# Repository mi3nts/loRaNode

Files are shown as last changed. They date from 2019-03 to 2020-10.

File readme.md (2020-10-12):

# LoRa Node 
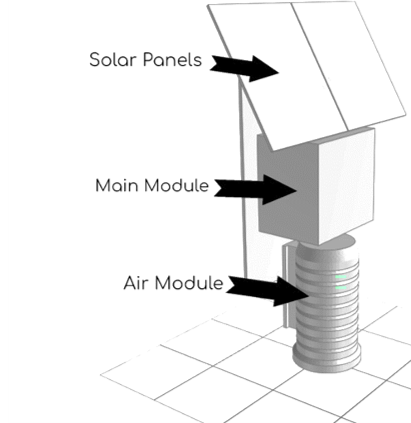
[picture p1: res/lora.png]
LoraNode

</br>
</br>

## A Guide to Using the Low-Cost Sensor Network
written by, Daniel Kiv (github: marchfori)

### Basics

1. Sensors Nodes (arduino)

### Sensors
2. Physical Characteristics
-Dimensions
-Weight
-Power Requirements

### Gateway Node (Raspberry Pi 3)
3.Useful Links

### Adjustments
4.Setting up the External Hard drive
5.Connecting to an external network
6.Adjustments to the PPD42NS

### Basics

The purpose of this documentation is to show how to start up and maintain the network
of low-cost sensors that will begin deployment in the North Texas area. With the increase
in particulate emissions over the years, there is a need to be aware of the implications
of toxic airbourne particles. These can have negative health outcomes on the population.
Currently, air quality sensors are spaced far and wide from each other collecting data at 
large time frames. They can also be often expensive. This project seeks to solve these 
issues and presents a low cost sensor network using a novel network communication known as
LoRaWAN, a set of arduinos, and a gateway linux based Raspbery Pi 3. Combined with the 
calibration technique using machine learning algorithms, this sensor network can effectively
provide the public with an accurate representation of air quality.

#### Sensor Nodes (arduino)
- Seeeduino w/ LoRaWAN and GPS capabilities

Uses a set of 10 arduino based nodes and 1 gateway Raspberry Pi 3.

- [Seeeduino LoRaWAN with GPS](https://www.google.com/search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)
- [Grove Dust Sensor](https://www.seeedstudio.com/Grove-Dust-Sensor-PPD42NS.html)
- [Grove Barometer Sensor: I2C protocol](https://www.seeedstudio.com/Grove-Barometer-Sensor-BMP28-p-2652.html)
- [Raspberry Pi 3 Model B](https://www.amazon.com/Raspberry-Pi-Model-Motherboard-Element/dp/B07CTF2GWR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)
- [RHFoM301 module: serves as the communication bridge for the Raspberry Pi 3](http://www.risinghf.com/#/product-details?product_id=6&lang=en%2F)
- [BME280 w/ Temperature, Pressure, & Humidity Readings](https://www.adafruit.com/product/2652?gclid=CJvFq_q63-ICFUi1wAod5RsHjw)
- [Grove Multichannel Gas Sensor](https://www.arrow.com/en/products/101020088/seeed-technology-limited?gclid=CKqP4Za73-ICFdm1wAodyJsA8g) 

## Sensors
These sensors are attached to the device

| Sensor Name | Description | Interface |
| ---- | ---- | ---- |
| Grove Dust Sensor | Measures low pulse occupancy time as a correlate to particular matter. | Digital Pin |
| Grove Barometer | Measures temperature (Celcius) and atmospheric pressure | I2C |
| Grove Multichannel Gas Sensor | Measures Carbon Monoxide, Nitrogen Dioxide, Ethanol, Hydrogen, Ammonia, Methane, Propane,and Isobutane in ppm. | I2C |

#### Physical Characteristics

**Dimensions** (L x W x H)
Seeduino device dimensions with add-ons: 65mm x 55mm x 45mm.
Gateway device dimensions (without antenna): 85mm x 55mm x 30mm.
Seeeduino device enclosure: 120mm x 120mm x 275 mm

**Weight**
Seeeduino device weight with add-ons: 0.25kg
Gateway device weight: 0.20kg
Seeeduino device with enclosure: 0.60kg

**Power Requirements**
Average power consumption on standby: 1.1W
Average power consumption during transmission 1.2W
Voltage usage: 4.91V
Current usage: 0.20A

- [3.7V Lithium Ion Battery](https://www.amazon.com/Lithium-Battery-Connector-LP803860-2000mAh/dp/B07CZFMFB3)
- [3W SEEED Solar Panel](https://cpc.farnell.com/seeed-studio/313070001/solar-panel-138x160-3w/dp/MK00376)

### Gateway Node (Raspberry Pi 3)

Used to collect signal broadcasts from surrounding nodes.

#### Useful links

[Here](https://github.com/mi3nts/loRaNode) is the link to the sensor node's software. 
If there are issues please contact me.

There is also software that synchornizes and creates the formatting for the data 
aggregation on the gateway node.

### Adjustments

#### Setting up the External hard drive

- Checking if the HD is connected 
```
sudo lshw -class disk -short 
```
Be sure the hard drive you want to use is formatted in the **_ext4_** filesystem. 

- Mounting the HD
```
sudo su
mount /dev/sda1 /mnt
```

- Transfer your root partition to the new drive:
```
sudo rsync -axv / /mnt
cp /boot/cmdline.txt /boot/cmdline.txt.bak
nano /boot/cmdline.txt

```
- Change the lines as follows:

```
dwc_otg.lpm_enable=0 console=serial0,115200 console=tty1 root=/dev/sda1 rootfstype=ext4 elevator=deadline fsck.repair=yes rootwait rootdelay=5
```
- Chnaging the Boot Order 
```
nano /mnt/etc/fstab
```
Then add the following line:
```
/dev/sda1       /               ext4    defaults,noatime  0       1
```
Make sure to get the spacing right 

Comment the SD Boot 
```
#/dev/mmcblk0p7  /               ext4    defaults,noatime  0       1

```

Then restart the system.

#### Connecting to an external network

```
sudo nano
/etcwpa_supplicant/wpa_supplicant.conf

   network={
    ssid="Test Wifi Network"
    psk="SecretPassWord"
    }
    
 sudo systemctl status pktfwd
 sudo systemctl enable pktfwd
 sudo systemctl restart pktfwd
 
 **mysql -u root -p**
 ```
 
#### Additional Modifications made to the PPD42NS
##### PPD42NS
shinyei
     <br/>
     
The pins are labeled as '**thresh**', '**P1**', '**+5v**', '**P2**, and '**grnd**'  going from left to write on the figure given above. 

 - Addition of a 10K resisitor between the threshold pin and ground:
 A good read on the mechanism followed is given [here](http://takingspace.org/wp-content/uploads/ShinyeiPPD42NS_Deconstruction_TracyAllen.pdf).
[useful](https://www.shadowandy.net/2015/05/arduino-dust-sensor.htm)
 -  Capable of dual output
 
 ##### color code
 
 - p1: green - D3
 - p2: blue - D4

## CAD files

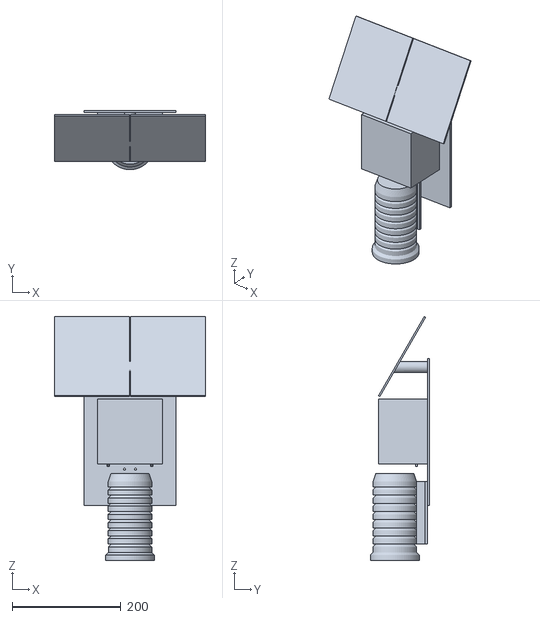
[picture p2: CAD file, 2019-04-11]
3D model/loRaNode2019.stl
278.0 x 109.0 x 448.5

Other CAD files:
3D model/loRaModel.fcstd

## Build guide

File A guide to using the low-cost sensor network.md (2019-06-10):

# A Guide to Using the Low-Cost Sensor Network
written by, Daniel Kiv (github: marchfori)

## Basics

1. Sensors Nodes (arduino)

## Sensors
2. Physical Characteristics
-Dimensions
-Weight
-Power Requirements

## Gateway Node (Raspberry Pi 3)
3.Useful Links

## Adjustments
4.Setting up the External Hard drive
5.Connecting to an external network
6.Adjustments to the PPD42NS

## Basics

The purpose of this documentation is to show how to start up and maintain the network
of low-cost sensors that will begin deployment in the North Texas area. With the increase
in particulate emissions over the years, there is a need to be aware of the implications
of toxic airbourne particles. These can have negative health outcomes on the population.
Currently, air quality sensors are spaced far and wide from each other collecting data at 
large time frames. They can also be often expensive. This project seeks to solve these 
issues and presents a low cost sensor network using a novel network communication known as
LoRaWAN, a set of arduinos, and a gateway linux based Raspbery Pi 3. Combined with the 
calibration technique using machine learning algorithms, this sensor network can effectively
provide the public with an accurate representation of air quality.

###### Sensor Nodes (arduino)
- Seeeduino w/ LoRaWAN and GPS capabilities

Uses a set of 10 arduino based nodes and 1 gateway Raspberry Pi 3.

- [Seeeduino LoRaWAN with GPS](https://www.google.com/search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)
- [Grove Dust Sensor](https://www.seeedstudio.com/Grove-Dust-Sensor-PPD42NS.html)
- [Grove Barometer Sensor: I2C protocol](https://www.seeedstudio.com/Grove-Barometer-Sensor-BMP28-p-2652.html)
- [Raspberry Pi 3 Model B](https://www.amazon.com/Raspberry-Pi-Model-Motherboard-Element/dp/B07CTF2GWR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)
- [RHFoM301 module: serves as the communication bridge for the Raspberry Pi 3](http://www.risinghf.com/#/product-details?product_id=6&lang=en%2F)
- [BME280 w/ Temperature, Pressure, & Humidity Readings](https://www.adafruit.com/product/2652?gclid=CJvFq_q63-ICFUi1wAod5RsHjw)
- [Grove Multichannel Gas Sensor](https://www.arrow.com/en/products/101020088/seeed-technology-limited?gclid=CKqP4Za73-ICFdm1wAodyJsA8g) 

## Sensors
These sensors are attached to the device

| Sensor Name | Description | Interface |
| ---- | ---- | ---- |
| Grove Dust Sensor | Measures low pulse occupancy time as a correlate to particular matter. | Digital Pin |
| Grove Barometer | Measures temperature (Celcius) and atmospheric pressure | I2C |
| Grove Multichannel Gas Sensor | Measures Carbon Monoxide, Nitrogen Dioxide, Ethanol, Hydrogen, Ammonia, Methane, Propane,and Isobutane in ppm. | I2C |

###### Physical Characteristics

**Dimensions** (L x W x H)
Seeduino device dimensions with add-ons: 65mm x 55mm x 45mm.
Gateway device dimensions (without antenna): 85mm x 55mm x 30mm.
Seeeduino device enclosure: 120mm x 120mm x 275 mm

**Weight**
Seeeduino device weight with add-ons: 0.25kg
Gateway device weight: 0.20kg
Seeeduino device with enclosure: 0.60kg

**Power Requirements**
Average power consumption on standby: 1.1W
Average power consumption during transmission 1.2W
Voltage usage: 4.91V
Current usage: 0.20A

- [3.7V Lithium Ion Battery](https://www.amazon.com/Lithium-Battery-Connector-LP803860-2000mAh/dp/B07CZFMFB3)
- [3W SEEED Solar Panel](https://cpc.farnell.com/seeed-studio/313070001/solar-panel-138x160-3w/dp/MK00376)

## Gateway Node (Raspberry Pi 3)

Used to collect signal broadcasts from surrounding nodes.

###### Useful links

[Here](https://github.com/mi3nts/loRaNode) is the link to the sensor node's software. 
If there are issues please contact me.

There is also software that synchornizes and creates the formatting for the data 
aggregation on the gateway node.

## Adjustments

###### Setting up the external hard drive

Be sure the hard drive you want to use is formatted in the **_ext4_** filesystem.
I used gparted. Then perform the following the commands in order to mount and 
transfer your root partition to the new drive:

```
sudo su
mount /dev/sda1 /mnt
sudo rsync -axv/ /mnt
cp /boot/cmdline.txt/boot/cmdline.txt.bak
nano /boot/cmdline.txt
```
Change the lines as follows:

```
dwc_otg.lpm_enable=0
console=serial0,115200 console=tty1
root=/dev/sda1 rootfstype=ext4 elevator=deadline
fsck.repair=yes rootwait rootdelay=5

nano /mnt/etc/fstab
```

Then add the following line:

```
/dev/sda1 / ext4
defaults,noatime 0

```

Then restart the system.

###### Connecting to an external network

```
sudo nano
/etcwpa_supplicant/wpa_supplicant.conf

   network={
    ssid="Test Wifi Network"
    psk="SecretPassWord"
    }
    
 sudo systemctl status pktfwd
 sudo systemctl enable pktfwd
 sudo systemctl restart pktfwd
 
 **mysql -u root -p**
 ```
 
 ######Adjustments to the PPD42NS
 
 [Diagram of PPD42NS](https://images.app.goo.gl/Z5E9UCeksRY98rgn6)
 
 The pins are labeled as 'thresh', 'P1', '+5V', 'P2', and 'grnd' going from left to right on the figure given above. Addition of a 10K resistor between the threshold pin and ground: A good read on the mechanism followed is given [here](http://takingspace.org/wp-content/uploads/ShinyeiPPD42NS_Deconstruction_TracyAllen.pdf)
 
- Capable of dual output

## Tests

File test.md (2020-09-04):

after first boot of the rasberi pi 
us: rxhf
pw: risinghf

# Expand SD
sudo raspi-config

# install Dependancies
```
sudo apt-get install screen
sudo apt-get install python3-pip
sudo pip3 install getmac
sudo pip3 install pyserial
sudo pip3 install netifaces
sudo pip3 install pynmea2
```
# Install crontab with Nano 
export VISUAL=nano; crontab -e

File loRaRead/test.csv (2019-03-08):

DateTime | NH3 | CO | NO2 | C3H8 | C4H10 | CH4 | H2 | C2H5OH | LowPulseOccupancy | lpoRatio | dustconc | Temperature | Pressure | Humidity
2.0 | 0.0 | 0.0 | 0.62 | 22.14 | 100712.0 | 16.0 | nan | nan
1.0 | 0.02 | 0.0 | 6.91 | 1.25 | 1423.63 | 865.82 | 3401.32 | 1.46
2.0 | 0.0 | 0.0 | 0.62 | 22.13 | 100711.0 | 16.0 | nan | nan
1.0 | 0.02 | 0.0 | 6.91 | 1.23 | 1384.14 | 845.38 | 3401.32 | 1.46
2.0 | 0.0 | 0.0 | 0.62 | 22.14 | 100712.0 | 16.0 | nan | nan
1.0 | 0.02 | 0.0 | 6.91 | 1.24 | 1403.69 | 855.51 | 3401.32 | 1.46
2.0 | 0.0 | 0.0 | 0.62 | 22.14 | 100710.0 | 16.0 | nan | nan
1.0 | 0.02 | 0.0 | 6.91 | 1.23 | 1384.14 | 845.38 | 3401.32 | 1.46
2.0 | 0.0 | 0.0 | 0.62 | 22.14 | 100714.0 | 16.0 | nan | nan
1.0 | 0.02 | 0.0 | 6.87 | 1.25 | 1423.63 | 865.82 | 3317.33 | 1.45
1.0 | 0.06 | 0.0 | 45.8 | 3.56 | 6919.4 | 3314.88 | 3720184.0 | 26.24
1.0 | 0.08 | 0.0 | 9.57 | 2.25 | 3466.94 | 1843.48 | 11353.08 | 2.41
2.0 | 10510.0 | 0.21 | 109.77 | 19.42 | 100748.0 | 20.0 | nan | nan
1.0 | 0.08 | 0.0 | 8.93 | 2.11 | 3140.91 | 1695.2 | 8782.5 | 2.16
2.0 | 0.0 | 0.0 | 0.62 | 19.44 | 100748.0 | 20.0 | nan | nan
1.0 | 0.09 | 0.0 | 8.5 | 2.01 | 2910.14 | 1588.84 | 7313.09 | 2.01
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

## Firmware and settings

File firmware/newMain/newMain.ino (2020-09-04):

/* 
 * Written by Daniel Kiv
 * Version 011020
 * 
 * Acknowledgements
 * Lakitha, Adam, Nora, Shrey
 */

#include <Arduino.h>
#include <Seeed_BME280.h>
#include <Wire.h>
#include <LoRaWan.h>
#include <avr/dtostrf.h>
#include "MutichannelGasSensor.h"
#include <SeeedOLED.h>
#include <Adafruit_INA219.h>
#include "SparkFun_SCD30_Arduino_Library.h"
#include "TinyGPS++.h"

// barometer initializations
double pressure;
BME280 baro;

Adafruit_INA219 inaSol(0x41);
Adafruit_INA219 inaBat(0x40);

//initialization of the SCD30 CO2 Sensor
SCD30 airSensor;

// initializations for dust sensor (global)
int pinP1 = 8;
int pinP2 = 7;

#define USE_GPS 1
#ifdef USE_GPS
TinyGPSPlus gps;
#endif

char buffer[256];
char id[10];

int DONEPIN = A4;

void setup() {
  SerialUSB.begin(115200);
  Serial2.begin(9600); // gps start 
//  oledInit();
//  SeeedOled.clearDisplay();
//  SeeedOled.setNormalDisplay();
//  SeeedOled.putString("Booting...");
  delay(2000);
  SerialUSB.println("System booting...");
  lora.init();
  lora.setDeviceReset();

  // sensor initializations ----------
  inaBat.begin();
  inaSol.begin();
  float batVoltage = inaBat.getBusVoltage_V();
  float solVoltage = inaSol.getBusVoltage_V();
  
  // check if the battery voltage is at threshold values
  checkBatteryStatus(batVoltage, solVoltage);
  gpsInit();
  dustInit();
  airSensor.begin(); 
  airSensor.setMeasurementInterval(30);
  baro.init();
  gasInit();

  // LoRaWAN initializations ------------------------
  memset(buffer, 0, 256);
  lora.getId(buffer, 256, 1);
  SerialUSB.print(buffer);
  readID(id, buffer);
  lora.setKey("2B7E151628AED2A6ABF7159999CF4F3C", "2B7E151628AED2A6ABF7159999CF4F3C", NULL);
  lora.setDeciveMode(LWABP);
  lora.setDataRate(DR3, US915HYBRID);
  lora.setChannel(0, 902.3);
  lora.setChannel(1, 902.5);
  lora.setChannel(2, 902.7);
//  lora.setChannel(3, 902.9, DR0, DR3);
//  lora.setChannel(4, 903.1, DR0, DR3);
//  lora.setChannel(5, 903.3, DR0, DR3);
//  lora.setChannel(6, 903.5, DR0, DR3);
//  lora.setChannel(7, 903.7, DR0, DR3);
  lora.setReceiceWindowFirst(0, 902.3);
  lora.setReceiceWindowSecond(923.3, DR3);
  lora.setAdaptiveDataRate(false);
  lora.setDutyCycle(false);
  lora.setJoinDutyCycle(false);
  lora.setPower(14);

  SerialUSB.println("System booted!");
}

void loop() {
  float batVoltage = inaBat.getBusVoltage_V();
  float solVoltage = inaSol.getBusVoltage_V();
  checkBatteryStatus(batVoltage, solVoltage);
  dataCycle();
}

void dataCycle() {
  bool result1, result2, result3, result4, result5 = false;
  char msg1[180] = "1,";
  char msg2[180] = "2,";
  char msg3[180] = "3,";
  char msg4[180] = "4,";
  char msg5[180] = "5,";
  char cat[15];
  char com[2] = ",";
  
  // collect data
  readPPD42NSMintsDuo(msg2, 15);
  double temperature = baro.getTemperature();
  double pressure = baro.getPressure();
  double humidity = baro.getHumidity();
  multiChan(msg1); // this function collects AND builds message
  readElectric(msg4);
  readCO2(msg5);
  
  // build message with correct precision
  append(temperature, msg3, 2);
  append(pressure, msg3, 2);
  append(humidity, msg3, 0);
  doGPS(msg3); // collect gps and append after

  // display data
//  screenDisplay(msg1, msg2, msg3, msg4, msg5);
  
  result1 = lora.transferPacket(msg1);
  SerialUSB.println(msg1);
  check(result1);
  result2 = lora.transferPacket(msg2);
  SerialUSB.println(msg2);
  check(result2);
  result3 = lora.transferPacket(msg3);
  SerialUSB.println(msg3);
  check(result3);
  result4 = lora.transferPacket(msg4);
  SerialUSB.println(msg4);
  check(result4);
  result5 = lora.transferPacket(msg5);
  SerialUSB.println(msg5);
  check(result5);
//  result = lora.transferPacket(data, 11);
  
//    memset(payload, '\0', 200);
}

void screenDisplay(char* msg1, char* msg2, char* msg3, char* msg4, char* msg5) {
  SeeedOled.clearDisplay();
  SeeedOled.setNormalDisplay();
  SeeedOled.setHorizontalScrollProperties(Scroll_Left,0,7,Scroll_5Frames);  //Set the properties of Horizontal Scrool
  SeeedOled.activateScroll();
  SeeedOled.setTextXY(0,0); 
  SeeedOled.putString(msg1);
  SeeedOled.setTextXY(1,0); 
  SeeedOled.putString(msg2);
  SeeedOled.setTextXY(2,0); 
  SeeedOled.putString(msg3);
  SeeedOled.setTextXY(3,0); 
  SeeedOled.putString(msg4);
  SeeedOled.setTextXY(4,0); 
  SeeedOled.putString(msg5);
}

void append(double data, char* msg, int precision) {
  char cat[15];
  char comma[2] = ",";
  
  dtostrf(data, 0, precision, cat);
  strcat(msg, cat);
  strcat(msg, comma);
}

void checkBatteryStatus(float batVoltage, float solVoltage) { 
  // checks whether there is enough sunlight based on the solar voltage
  // and then checks the battery voltage to decide if the sensor
  // must intialize a sleep state, in order to replenish battery
  
  batVoltage = abs(batVoltage);
  solVoltage = abs(solVoltage);

  // when the battery voltage is close to overdischarging, sleep
  if (batVoltage < 3.00) {
    SerialUSB.println("Voltage LOW!");
//    SeeedOled.clearDisplay();
//    SeeedOled.setNormalDisplay();
//    SeeedOled.setTextXY(0,0); 
//    SeeedOled.putString("Voltages LOW!");
//    SeeedOled.setTextXY(0,0); 
//    SeeedOled.putString("battery voltage:");
//    SeeedOled.setTextXY(1,0); 
//    SeeedOled.putNumber(batVoltage);
//    SeeedOled.setTextXY(0,0); 
//    SeeedOled.putString("solar voltage:");
//    SeeedOled.setTextXY(2,0); 
//    SeeedOled.putNumber(solVoltage);
    delay(1000);
    digitalWrite(DONEPIN, HIGH);
    delay(1);
    digitalWrite(DONEPIN, LOW);
    delay(1);
  }
  
  // when night, if voltage is too low, sleep until battery voltage increases
  if (solVoltage < 5.50 && batVoltage < 3.10) {
    SerialUSB.println("Voltage LOW!");
//    SeeedOled.clearDisplay();
//    SeeedOled.setNormalDisplay();
//    SeeedOled.setTextXY(0,0); 
//    SeeedOled.putString("Voltages LOW!");
//    SeeedOled.setTextXY(0,0); 
//    SeeedOled.putString("battery voltage:");
//    SeeedOled.setTextXY(1,0); 
//    SeeedOled.putNumber(batVoltage);
//    SeeedOled.setTextXY(0,0); 
//    SeeedOled.putString("solar voltage:");
//    SeeedOled.setTextXY(2,0); 
//    SeeedOled.putNumber(solVoltage);
    delay(1000);
    digitalWrite(DONEPIN, HIGH);
    delay(1);
    digitalWrite(DONEPIN, LOW);
    delay(1);
  }
}

void appendLast(double data, char* msg, int precision) {
  char cat[15];
  
  dtostrf(data, 0, precision, cat);
  strcat(msg, cat);
}

void normalPower() {
  for(unsigned char i = 7; i < 9; i ++) {
    // pinMode(i, OUTPUT);
    digitalWrite(i, HIGH);
  }
  lora.setDeviceReset();
}

void dummy(void)
{
    // do something
}

void readID(char* id, char* buffer) {
  char comma[2] = ",";
  
  id[0] = buffer[14];
  id[1] = buffer[15];
  id[2] = buffer[17];
  id[3] = buffer[18];
  id[4] = buffer[20];
  id[5] = buffer[21];
  id[6] = buffer[23];
  id[7] = buffer[24];
  strcat(id, comma);
}

void check(bool result) {
  if(result) {
    short length;
    short rssi;
    
    memset(buffer, 0, 256);
    length = lora.receivePacket(buffer, 256, &rssi);
    SeeedOled.setTextXY(6,0);
    SeeedOled.putString("NOTICE: BRDCST!");
    if(length) {
      Serial.print("Length is: ");
      Serial.println(length);
      Serial.print("RSSI is: ");
      Serial.println(rssi);
      Serial.print("Data is: ");
      for(unsigned char i = 0; i < length; i++) {
        Serial.print("0x");
        Serial.print(buffer[i], HEX);
        Serial.print(" ");
      }
      Serial.println();
    }
    delay(100);
  }
}

void doGPS(char* msg) {
  double latitude;
  double longitude;
  double dateStamp;
  double timeStamp;
  
  if (gps.location.isValid()) {
    char cat[15];
    
//    timeStamp = gps.time.value();
//    dateStamp = gps.date.value();
    latitude = gps.location.lat();
    longitude = gps.location.lng();
  
//    dtostrf(dateStamp, 0, 0, cat);
//    strcat(msg, cat);
//    append(timeStamp, msg, 0); // fix time FIRST 
    strcat(msg, "nan,");
    append(latitude, msg, 6);
    appendLast(longitude, msg, 6);
  }
  else {
    latitude = 0;
    longitude = 0;
    timeStamp = 0;
    dateStamp = 0;
    strcat(msg, "nan,nan,nan");
  }
}

void multiChan(char* msg) {
  double conc;
  
  conc = gas.measure_NH3();
  validConc(conc, msg);

  conc = gas.measure_CO();
  validConc(conc, msg);

  conc = gas.measure_NO2();
  validConc(conc, msg);

  conc = gas.measure_C3H8();
  validConc(conc, msg);

  conc = gas.measure_C4H10();
  validConc(conc, msg);

  conc = gas.measure_CH4();
  validConc(conc, msg);

  conc = gas.measure_H2();
  validConc(conc, msg);

  conc = gas.measure_C2H5OH();
  if(conc >= 0) {
      appendLast(conc, msg, 2);
    }
    else {
      strcat(msg, "nan");
    }
}

void validConc(double conc, char* msg) {
  char nan[5] = "nan,";
  
  if(conc >= 0) {
    append(conc, msg, 2);
  }
  else {
    strcat(msg, nan);
  }
}

void readCO2(char *msg){
  float co2Lvl = airSensor.getCO2();
  float co2Temp = airSensor.getTemperature();
  float co2Humd = airSensor.getHumidity();

  SerialUSB.print("CO2 Level (ppm) "); SerialUSB.println(airSensor.getCO2());
  SerialUSB.print("Temperature (C) "); SerialUSB.println(airSensor.getTemperature());
  SerialUSB.print("Humidity (%) "); SerialUSB.println(airSensor.getHumidity());

  append(co2Lvl, msg, 0);
  append(co2Temp, msg, 2);
  appendLast(co2Humd, msg, 2);
}

void readElectric(char *msg) {
  float shuntVoltageBat  = inaBat.getShuntVoltage_mV();
  float busVoltageBat    = inaBat.getBusVoltage_V();
  float currentMaBat     = inaBat.getCurrent_mA();
//  float powerMwBat      = inaBat.getPower_mW();
  float shuntVoltageSol  = inaSol.getShuntVoltage_mV();
  float busVoltageSol    = inaSol.getBusVoltage_V();
  float currentMaSol     = inaSol.getCurrent_mA();
//  float powerMwSol      = inaSol.getPower_mW();

  SerialUSB.print("Bat Bus Voltage(V) "); SerialUSB.println(inaBat.getBusVoltage_V());
  SerialUSB.print("Bat Shunt Voltage(mV) "); SerialUSB.println(inaBat.getShuntVoltage_mV());
  SerialUSB.print("Bat Current(mA) "); SerialUSB.println(inaBat.getCurrent_mA());
//  Serial.print("Bat Power(mW) "); Serial.println(inaBat.getPower_mW());
  SerialUSB.print("Sol Bus Voltage(V) "); SerialUSB.println(inaSol.getBusVoltage_V());
  SerialUSB.print("Sol Shunt Voltage(mV) "); SerialUSB.println(inaSol.getShuntVoltage_mV());
  SerialUSB.print("Sol Current(mA) "); SerialUSB.println(inaSol.getCurrent_mA());
//  Serial.print("Sol Power(mW) "); Serial.println(inaSol.getPower_mW());

  append(shuntVoltageBat, msg, 2);
  append(busVoltageBat, msg, 2);
  append(currentMaBat, msg, 2);
//  append(powerMwBat, msg, 2);
  append(shuntVoltageSol, msg, 2);
  append(busVoltageSol, msg, 2);
  appendLast(currentMaSol, msg, 2);
//  append(powerMwSol, msg, 2);
}

void readPPD42NSMintsDuo(char *msg, uint8_t sampleTimeSeconds) {
  unsigned long starttime;
  unsigned long sampletime_ms = sampleTimeSeconds*1000;

  float ratioPmMid   = 0;
  float ratioPm10  = 0;
  
  float concentrationPmMid = 0;
  float concentrationPm2_5 = 0;
  float concentrationPm10  = 0;

  boolean pmMidPinValue = HIGH;
  boolean pm10PinValue = HIGH;
  
  boolean pmMidReading  = false;
  boolean pm10Reading  = false;
  
  unsigned long LPOPmMid  =  0;
  unsigned long LPOPm10 =  0;
  
  unsigned long readingTimePmMid   =  0;
  unsigned long readingTimePm10  =  0;
  
  starttime = millis();

  while ((millis() - starttime) < sampletime_ms)
  {
     pmMidPinValue =  digitalRead(pinP1);
     pm10PinValue  =  digitalRead(pinP2);

//      For Mid Range Readings 
     if(pmMidPinValue == LOW && pmMidReading == false) {
        pmMidReading = true;
        readingTimePmMid = micros();
     }
    
     if(pmMidPinValue == HIGH && pmMidReading == true) {
        LPOPmMid = LPOPmMid + (micros() - readingTimePmMid);
        pmMidReading = false;
     }

//      For PM 10 Readings
     if(pm10PinValue == LOW && pm10Reading == false) {
        pm10Reading = true;
        readingTimePm10 = micros();
     }
    
     if(pm10PinValue == HIGH && pm10Reading == true) {
       LPOPm10 = LPOPm10 + (micros() - readingTimePm10);
       pm10Reading = false;
     }
 
  }// WHILE LOOP END 
  
  ratioPmMid  = LPOPmMid/(sampletime_ms*10.0);
  ratioPm10   = LPOPm10/(sampletime_ms*10.0);

  concentrationPmMid = 1.1*pow(ratioPmMid,3)-3.8*pow(ratioPmMid,2)+520*ratioPmMid+0.62; // using spec sheet curve
  concentrationPm10  = 1.1*pow(ratioPm10,3)-3.8*pow(ratioPm10,2)+520*ratioPm10+0.62; // using spec sheet curve
  concentrationPm2_5 = concentrationPm10 - concentrationPmMid ;

  append(LPOPmMid, msg, 0);
  append(ratioPmMid, msg, 2);
  append(concentrationPmMid, msg, 2);
  append(LPOPm10, msg, 0);
  append(ratioPm10, msg, 2);
  appendLast(concentrationPm10, msg, 2);
  
  SerialUSB.print("lpoMID; "); SerialUSB.println(LPOPmMid);
  SerialUSB.print("ratMid; "); SerialUSB.println(ratioPmMid);
  SerialUSB.print("cPmMid; "); SerialUSB.println(concentrationPmMid);
  SerialUSB.print("lpoPM10; "); SerialUSB.println(LPOPm10);
  SerialUSB.print("ratPM10; "); SerialUSB.println(ratioPm10);
  SerialUSB.print("cPm10; "); SerialUSB.println(concentrationPm10);
  SerialUSB.print("cPm25; "); SerialUSB.println(concentrationPm2_5);

}

void dustInit() {
  pinMode(pinP1,INPUT); // pin from global
  pinMode(pinP2,INPUT);
}

void oledInit() {
  SeeedOled.init();
  SeeedOled.clearDisplay();
  SeeedOled.setNormalDisplay();
  SeeedOled.setPageMode(); 
  SeeedOled.setTextXY(0,0);
}

void gasInit() {
  gas.begin(0x04);
  gas.powerOn();
}

void gpsInit() {
     char c;
#ifdef USE_GPS
   bool locked;
#endif
  
  #ifdef USE_GPS
    Serial2.begin(9600);     // open the GPS
    locked = false;

    while (!gps.location.isValid()) {
      while (Serial2.available() > 0) {
        if (gps.encode(c=Serial2.read())) {
          if (gps.location.isValid()) {
            break;
          }
        }
        // SerialUSB.print(c);
      }

//      if (locked)
//        break;

      if (millis() > 15000 && gps.charsProcessed() < 10)
      {
        SerialUSB.println(F("No GPS detected: check wiring."));
        SerialUSB.println(gps.charsProcessed());
        break;
      } 
      else if (millis() > 20000) {
        SerialUSB.println(F("Not able to get a fix in alloted time."));     
        break;
      }
    }
#endif
}

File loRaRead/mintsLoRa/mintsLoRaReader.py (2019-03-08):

import serial
import datetime
import os
import csv
import deepdish as dd
from mintsLoRa import mintsLoRaLatest as mLL
from mintsLoRa import mintsLoRaDefinitions as mLD
from getmac import get_mac_address
import time
import serial
import pynmea2
from collections import OrderedDict
import netifaces as ni


# macAddress    = mD.macAddress
dataFolder    = mLD.dataFolder
latestOff     = mLD.latestOff


def LORAWrite(sensorData,dateTime,loRaID):
    sensorName = "LORA"
    dataLength = 19
    print(len(sensorData))
    if(len(sensorData) == (dataLength)):
        sensorDictionary =  OrderedDict([
                ("dateTime"     , str(dateTime)),
                ("timestamp"          ,sensorData[0]),
                ("latitude"           ,sensorData[1]),
                ("longitude"          ,sensorData[2]),
                ("altitude"           ,sensorData[3]),
        	    ("lowPulseOccupancy"  ,sensorData[4]),
            	("concentration"      ,sensorData[5]),
                ("ratio"              ,sensorData[6]),
                ("timeSpent"          ,sensorData[7]),
        		("temperature"        ,sensorData[8]),
            	("pressure"           ,sensorData[9]),
                ("humidity"           ,sensorData[10]),
        		("nh3"        ,sensorData[11]),
            	("co"         ,sensorData[12]),
                ("no2"        ,sensorData[13]),
            	("c3h8"       ,sensorData[14]),
        		("c4h10"      ,sensorData[15]),
            	("ch4"        ,sensorData[16]),
                ("h2"         ,sensorData[17]),
            	("c2h5oh  "   ,sensorData[18]),
                ])

        sensorFinisherLora(dateTime,loRaID,sensorDictionary)


def sensorFinisherLora(dateTime,loRaID,sensorDictionary):
    #Getting Write Path
    writePath = getWritePathLoRa(loRaID,dateTime)
    exists = directoryCheck(writePath)
    writeCSV2(writePath,sensorDictionary,exists)
    print(writePath)
    if(not(latestOff)):
       mL.writeHDF5Latest(writePath,sensorDictionary,sensorName)
    print("-----------------------------------")
    print(loRaID)
    print(sensorDictionary)


def getWritePathLoRa(loRaID,dateTime):
    #Example  : MINTS_0061_OOPCN3_2019_01_04.csv
    writePath = dataFolder+"/"+loRaID+"/"+str(dateTime.year).zfill(4)  + "/" + str(dateTime.month).zfill(2)+ "/"+str(dateTime.day).zfill(2)+"/"+ "MINTS_LoRa_"+ loRaID+ "_" + str(dateTime.year).zfill(4) + "_" +str(dateTime.month).zfill(2) + "_" +str(dateTime.day).zfill(2) +".csv"
    return writePath;


def directoryCheck(outputPath):
    exists = os.path.isfile(outputPath)
    directoryIn = os.path.dirname(outputPath)
    if not os.path.exists(directoryIn):
        os.makedirs(directoryIn)
    return exists


def writeCSV2(writePath,sensorDictionary,exists):
    keys =  list(sensorDictionary.keys())
    with open(writePath, 'a') as csv_file:
        writer = csv.DictWriter(csv_file, fieldnames=keys)
        # print(exists)
        if(not(exists)):
            writer.writeheader()
        writer.writerow(sensorDictionary)

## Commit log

2019-04-11 3D Model Added
    [loRaModel.fcstd, loRaNode2019.stl]
2019-04-11 Upload 3D modified
    [loRaModel.fcstd, loRaNode2019.stl]
2019-06-10 Create A guide to using the low-cost sensor network
2019-06-10 Rename A guide to using the low-cost sensor network to A guide to using the low-cost sensor network.md
2019-06-10 Update A guide to using the low-cost sensor network.md
2020-01-14 voltage checks
